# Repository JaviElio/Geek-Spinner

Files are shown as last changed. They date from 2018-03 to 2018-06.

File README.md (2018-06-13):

# Geek-Spinner
POV Spinner

Based on this project: 
	
	- Title:	GEEK SPINNER	
	- Author:	MakersBox
	- Link:		http://www.instructables.com/id/Geek-Spinner/

**BOM**

	- Attiny84-20SSU
	- 8 x 3 mm Red leds
	- SMD Blue led
	- 8 x 330mOhms resistors
	- Push button
	- CR2032 battery holder: 	https://lcsc.com/product-detail/Battery-Holders-Clips-Contacts_CR2032Curved-feet-3V_C70373.html
	- 2 x 0.1uF capacitors
	- TLE4906 Hall sensor: 		https://lcsc.com/product-detail/Sensors_Infineon_TLE4906KHTSA1_TLE4906KHTSA1_C126652.html
	- SMD switch : 			https://lcsc.com/product-detail/Toggle-Switches_9mm-3-5mm_C92658.html
	- 2x3 header: 			https://lcsc.com/product-detail/Male-Header_Headers-Pins-2-3P-2-54mm-SMD_C124390.html
	- 608 bearing: 			https://www.aliexpress.com/item/New-High-Speed-608-Hybrid-Ceramic-Center-Bearing-For-Fidget-Hand-spinner-ToyBBC/32817310812.html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
	- 2x1mm neodynium magnet:	https://www.aliexpress.com/item/Free-shipping-10PCS-magnets-2mmx1mm-Tiny-Disc-Neodymium-Rare-Earth-Magnet-2x1-Craft-Model-2-1/32719568312.html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

**3D Model**

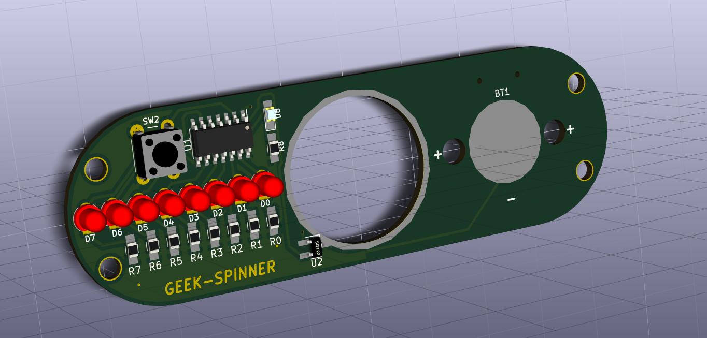
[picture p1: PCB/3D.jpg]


**Video**

POV Spinner (https://www.youtube.com/watch?v=f8Oj__So2bI "POV Spinner")

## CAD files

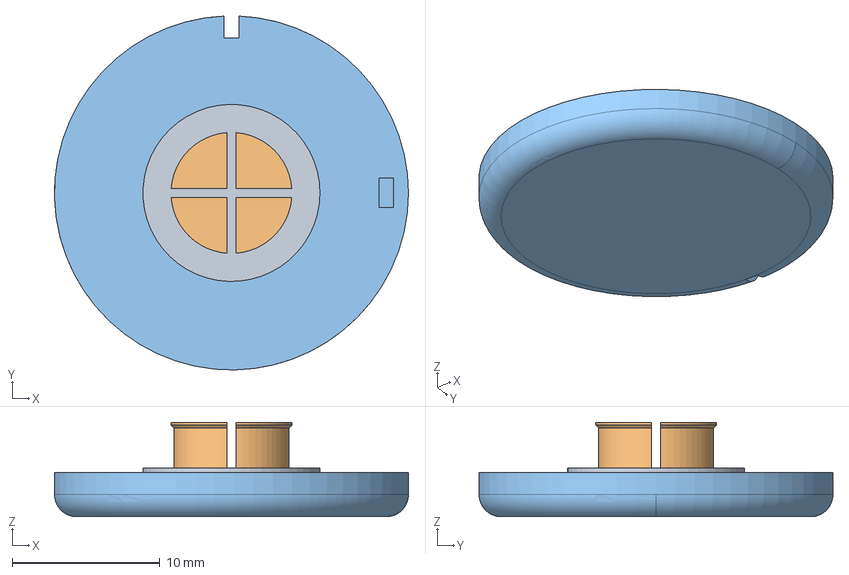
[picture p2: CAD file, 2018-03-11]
Caps/Cap_24mm.fcstd
24.0 x 24.0 x 6.40 mm
Cilindro001

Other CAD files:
Caps/Cap_24mm.stl

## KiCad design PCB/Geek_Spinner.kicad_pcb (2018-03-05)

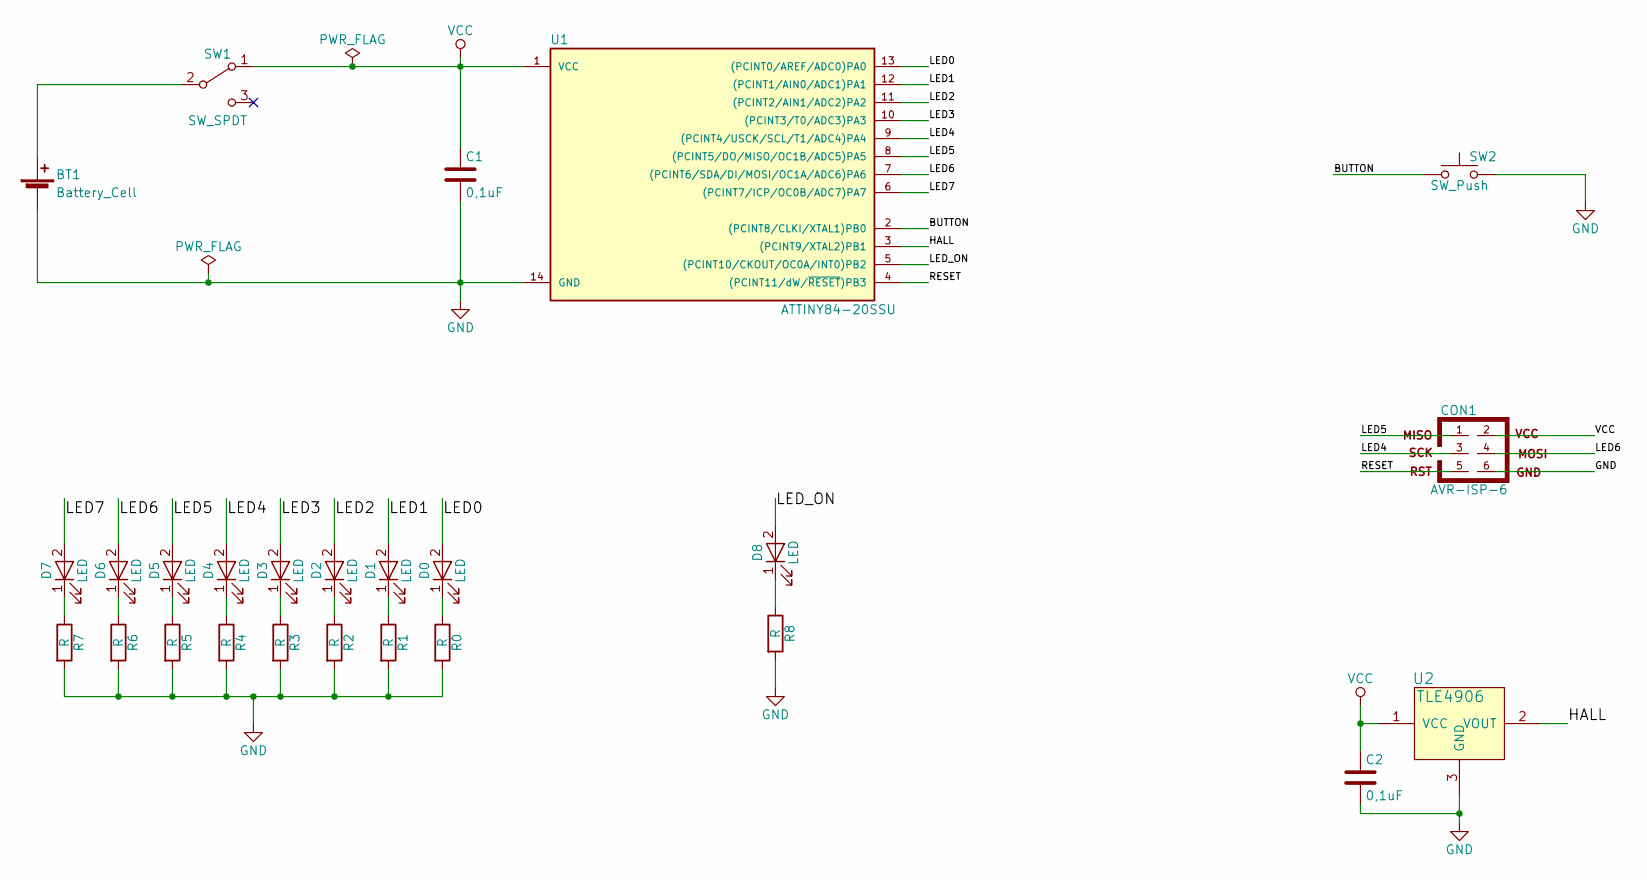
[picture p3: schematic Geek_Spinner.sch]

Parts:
BT1: Battery_Cell; CR2032_Holder_THT
C1, C2: 0,1uF; C_0805_HandSoldering
CON1: AVR-ISP-6; Pin_Header_Straight_2x03_Pitch2.54mm_SMD
D0, D1, D2, D3, D4, D5, D6, D7: LED; LED_D3.0mm
D8: LED; LED_0805_HandSoldering
R0, R1, R2, R3, R4, R5, R6, R7, R8: R; R_0805_HandSoldering
SW1: SW_SPDT; SW_SPDT_CK-JS102011SAQN
SW2: SW_Push; SW_PUSH_6mm_h4.3mm
U1: ATTINY84-20SSU; SOIC-14_3.9x8.7mm_Pitch1.27mm
U2: TLE4906; SC-59_Handsoldering

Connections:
/BUTTON: SW2.1, U1.2 ((PCINT8/CLKI/XTAL1)PB0)
/HALL: U1.3 ((PCINT9/XTAL2)PB1), U2.2 (VOUT)
/LED0: D0.2 (A), U1.13 ((PCINT0/AREF/ADC0)PA0)
/LED1: D1.2 (A), U1.12 ((PCINT1/AIN0/ADC1)PA1)
/LED2: D2.2 (A), U1.11 ((PCINT2/AIN1/ADC2)PA2)
/LED3: D3.2 (A), U1.10 ((PCINT3/T0/ADC3)PA3)
/LED4: CON1.3, D4.2 (A), U1.9 ((PCINT4/USCK/SCL/T1/ADC4)PA4)
/LED5: CON1.1, D5.2 (A), U1.8 ((PCINT5/DO/MISO/OC1B/ADC5)PA5)
/LED6: CON1.4, D6.2 (A), U1.7 ((PCINT6/SDA/DI/MOSI/OC1A/ADC6)PA6)
/LED7: D7.2 (A), U1.6 ((PCINT7/ICP/OC0B/ADC7)PA7)
/LED_ON: D8.2 (A), U1.5 ((PCINT10/CKOUT/OC0A/INT0)PB2)
/RESET: CON1.5, U1.4 ((PCINT11/dW/~RESET~)PB3)
GND: BT1.2 (-), C1.2, C2.2, CON1.6, R0.2, R1.2, R2.2, R3.2, R4.2, R5.2, R6.2, R7.2, R8.2, SW2.2, U1.14 (GND), U2.3 (GND)
unnamed: BT1.1 (+), SW1.2 (B)
unnamed: D0.1 (K), R0.1
unnamed: D1.1 (K), R1.1
unnamed: D2.1 (K), R2.1
unnamed: D3.1 (K), R3.1
unnamed: D4.1 (K), R4.1
unnamed: D5.1 (K), R5.1
unnamed: D6.1 (K), R6.1
unnamed: D7.1 (K), R7.1
unnamed: D8.1 (K), R8.1
VCC: C1.1, C2.1, CON1.2, SW1.1 (A), U1.1 (VCC), U2.1 (VCC)

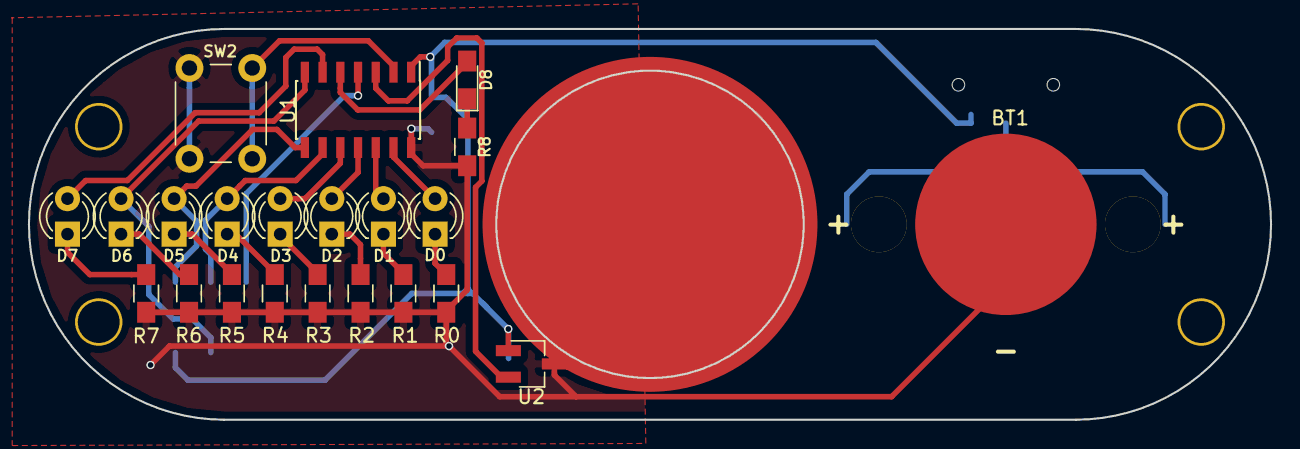
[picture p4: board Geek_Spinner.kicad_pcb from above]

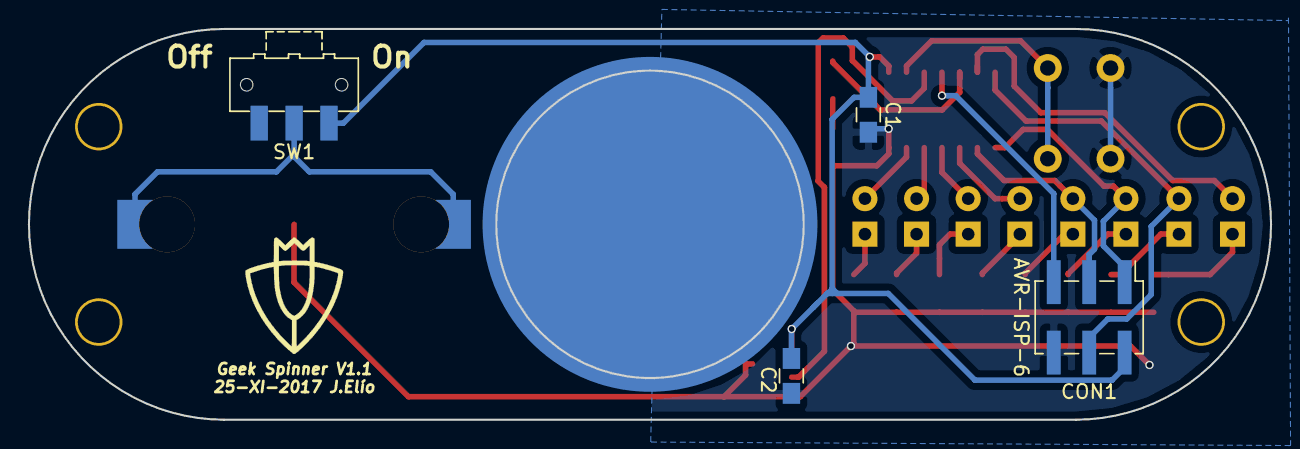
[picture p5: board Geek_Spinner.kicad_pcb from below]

Board: 2 copper layers, 89.0 x 28.0 mm, 26 parts (4 on the bottom side), 24 nets.

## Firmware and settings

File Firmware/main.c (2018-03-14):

/*
 * GeekSpinner.c
 *
 * Created: 21/11/2017 19:54:01
 * Author : javie
 */ 
#define F_CPU	8000000UL

#include <avr/io.h>
#include <stdio.h>
#include <util/delay.h>
#include <avr/interrupt.h>
#include <avr/pgmspace.h>
#include <avr/sleep.h>
#include <avr/wdt.h>
#include "font.h"
#include "textAndShapes.h"


uint8_t spinning = 0;							// spinning -> 1 / not spinning -> 0
volatile uint8_t magnetFlag = 0;				// hall sensor activation flag
uint8_t mode = 1;								// Led mode

volatile uint16_t revs = 0;						// total revolutions
char revsString[6]= "";							// total revolutions (string)
char rpmString[6]="";							// rpm (string)
volatile uint16_t timer0_OV = 0;				// timer overflow counter
volatile uint16_t oldTimer0_OV = 800;			// previous overflow counter
volatile uint16_t millisRev = 0;				// milliseconds per revolution. 


// Magnet sensed interrupt
// calculate time per revolution
ISR (PCINT1_vect) {								// magnet sensed
	if (!(PINB & ( 1 << PINB1))) {

		millisRev = timer0_OV * 0.256;			// Calculate microseconds per revolution
		oldTimer0_OV = timer0_OV;				// Keep overflow counter
		timer0_OV = 0;							// Reset overflow counter
		
		revs++;									// increase revolutions counter
		magnetFlag = 1;							// flag "magnet sensed"
	}
}

// Timer 0 overflow interrupt
// Used to calculate timer per revolution
ISR	(TIM0_OVF_vect) {
	timer0_OV++;
	if (timer0_OV>65500) timer0_OV=65500;
}


ISR(WDT_vect) {

	wdt_disable();  // disable watchdog
}


// Change spinner mode when button is pressed
void ChangeMode(void){							// Change spinner mode
	
	mode++;
	spinning = 0;
	magnetFlag = 0;								
	
	if (mode < 1 || mode > 8) mode = 1;			// Check boundaries
	
	while (!(PINB & (1 << PINB0))) {			// Wait until button is released
		PORTA = (1 << (mode -1));				// Show active mode while button is pressed
		PORTB &= ~(1 << PB2);					// Blue led off
		_delay_ms(50);
	}

	PORTA = 0x00;								// Switch off leds
	PORTB |= (1 << PB2);						// Blue led off
}

// Returns delay in us
uint16_t CalculateDelay(uint16_t inputMillis) {

	return (uint16_t) inputMillis*9.1;
}

// custom delay
void Delay_Us (uint16_t n) {
	
	while(n--) {
		_delay_us(1);
	}
}


//Delay to print lower text
//Functions needs number of character of first line
void DelayLowerText(uint8_t charsFirstLine, uint16_t calculatedDelay) {
	
	// (5 columns x 6 characters) x calculatedDelay;
	Delay_Us( 5*(6-charsFirstLine)*calculatedDelay);
	
}

// Returns number of digits of a given int variable
int8_t NumberOfDigits(uint16_t number) {

	if (number<10) return 1;
	if (number<100) return 2;
	if (number<1000) return 3;
	if (number<10000) return 4;
	if (number<100000) return 5;
	
}


// Print shapes
void ShowShape( const char shape[], uint8_t shapeSize, uint16_t delay){

	for ( int idx=0; idx< shapeSize; idx++)
	{
		PORTA = pgm_read_byte_near(shape+idx);
		Delay_Us(delay);
	}
	
	PORTA = 0x00;
	
};

// Print upper text
void ShowUpperText(const char text[], uint8_t textSize, uint16_t delay) {

	for(int ch=0; ch < textSize; ch++) {										// iterates over each character
				
		for (int col=0; col < 5; col++)											// iterate over each column
		{
			uint8_t column = pgm_read_byte_near(&(font[text[ch]-32][col]));
					
			for (int dot=0; dot < 8; dot++)										// iterate over each dot
			{
				// Swap bits
				if (column & (1 << dot)) PORTA |= (uint8_t) (0x80 >> dot);		// (uint8_t) is necessary,if not the byte is filled with '1'
			}
			Delay_Us(delay);
			PORTA = 0x00;
		}
				
		Delay_Us(delay);
				
	}
}

// Print lower text
void ShowLowerText(const char text[], uint8_t textSize, uint16_t delay) {

	for (int ch = textSize-2; ch>=0; ch--) {									// iterates over each character
		for (int col=4; col>=0; col--)											// iterates over each column
		{
			PORTA = pgm_read_byte_near(&(font[text[ch]-32][col]));
			Delay_Us(delay);
			PORTA=0x00;
		}
		Delay_Us(delay);
	}
}



int main(void)
{

	// Set I/O
	DDRA	=	0xFF;					// PORTA outputs (red leds)
	DDRB	|=	(1 << PB2);				// PB2 output (blue led)
 	DDRB	&=	~(1 << DDB0);			// PB0 input (Button)
 	DDRB	&=  ~(1 << DDB1);			// PB1 input (Hall Sensor)
	PORTB	|=	(1 << PB0);				// Pull-Up resistor
	PORTB	|=	(1 << PB1);				// Pull-Up resistor	

	// Set Timer0
	TCCR0B	|=	(1 << CS01);			// Start timer0 and set prescaler clk/8
	TIMSK0	|=	(1 << TOIE0);			// Enable Overflow Interrupt

	// Reduce power consumption
	ACSR |= (1 << ACD);										// Disable ADC
	PRR	 |= (1 << PRTIM1) | (1 << PRUSI) | (1 << PRADC);	// Disable Timer1, USI and ADC
	set_sleep_mode(SLEEP_MODE_PWR_DOWN);

	// Set interrupt
	PCMSK1	|=	(1 << PCINT9);			// Enable pin interrupt at PB1
	GIMSK	|=	(1 << PCIE1);			// Enable pin change interrupt 1
	sei();								// Enable global interrupts
	
	
	
	
    /* Replace with your application code */
    while (1) 
    {
		
				
		// Change spinner mode
		if (!(PINB & (1 << PINB0)))	ChangeMode();


		
		// If speed is low -> not spinning
		if (oldTimer0_OV >= 800 || timer0_OV > 800)
		{
			spinning = 0;
			PORTB |= (1 << PB2);						// Blue led on
		}
		 else if (oldTimer0_OV < 800)
		 {
			 spinning = 1;
			 PORTB &= ~(1 << PB2);						// Blue led off
		 }
	
	
		 
		 // If spinner is stopped during 16s. (aprox) then sleep
		 if (timer0_OV >= 65500) {
			
			PORTB &= ~(1 << PB2);									// Blue led off
			WDTCSR |= (1 << WDCE) | (1 << WDE);						// Enable WatchDog
			WDTCSR |= (1 << WDIE) | (1 << WDP3);					// Set prescaler to 4s

			sleep_mode();								// go to sleep

			PORTB |= (1 << PB2);						// Blue led on
			_delay_ms(15);
			PORTB &= ~(1 << PB2);						// Blue led off	

		 }
				
	
		
				///////////////////
				// Spinner modes //
				///////////////////


		// Lily pad
		if (mode==1 && spinning==1){
	
			for (int Led=0; Led<8; Led++)
			{
				PORTA = 1 << Led;
				_delay_ms(1);
			}
	
			for (int Led=7; Led > 0;Led--)
			{
				PORTA = 1 << Led;
				_delay_ms(1);
			}

			PORTA = 0x00;

		}		

		
		
		// Smiley
		if (mode==2 && magnetFlag==1 && spinning==1)
		{

			uint16_t calculatedDelay = CalculateDelay(millisRev);	// Calculate delay
			ShowShape(shape_2, sizeof(shape_2), calculatedDelay);	// Show shape
			magnetFlag=0;


		}
	
		
		// Fan
		if (mode==3 && magnetFlag==1 && spinning==1)
		{
			uint16_t calculatedDelay = CalculateDelay(millisRev);	// Calculate delay
			ShowShape(shape_3, sizeof(shape_3), calculatedDelay);	// Show shape
			magnetFlag=0;

		}

	
		
		
		// Heart
		if (mode==4 && spinning == 1 && magnetFlag== 1)
		{

			uint16_t calculatedDelay = CalculateDelay(millisRev);	// Calculate delay
			ShowShape(shape_1, sizeof(shape_1), calculatedDelay);	// Show shape
			magnetFlag=0;

		}		
		
						

		// RPM
		if (mode==5 && magnetFlag==1 && spinning==1){
			
			uint16_t calculatedDelay = CalculateDelay(millisRev);				// Calculate delay
			
			uint16_t rpm = (oldTimer0_OV *0.256);
			rpm = 60000 / rpm;													// Calculate rpm
			sprintf(rpmString, "%d", rpm);										// rpm(int) to string

			ShowUpperText(rpmString, NumberOfDigits(rpm), calculatedDelay);		// Print upper text
			DelayLowerText(NumberOfDigits(rpm), calculatedDelay);				// Wait to print lower text
			ShowLowerText(rpmText,sizeof(rpmText), calculatedDelay);			// Print lower text
			magnetFlag = 0;
			
			
			
		}


		// Total revolutions
		if (mode==6 && magnetFlag ==1 && spinning ==1) {
			
			uint16_t calculatedDelay = CalculateDelay(millisRev);				// Calculate delay for this revolution
			sprintf(revsString, "%d", revs);									// change "int" variable to string

			ShowUpperText(revsString, NumberOfDigits(revs), calculatedDelay);	// Print upper text
			DelayLowerText(NumberOfDigits(revs), calculatedDelay);				// Wait to print lower text
			ShowLowerText(revText, sizeof(revText), calculatedDelay);			// Print lower text
			magnetFlag = 0;
			
		}


		// TEXT		
		if (mode==7 && magnetFlag == 1 && spinning==1) {
			
			uint16_t calculatedDelay = CalculateDelay(millisRev);				// Calculate delay for this revolution

			ShowUpperText(upperText, sizeof(upperText)-1, calculatedDelay);		// Print upper text
			Delay_Us(calculatedDelay*3);										// Delay to print lower text
			ShowLowerText(lowerText, sizeof(lowerText), calculatedDelay);		// Print lower text
			magnetFlag = 0;
			
		}

		if (mode==8 && magnetFlag == 1 && spinning==1) {
			
			static uint8_t repetitionCouneter = 0;
			if (repetitionCouneter>80) repetitionCouneter = 0;

			uint16_t calculatedDelay = CalculateDelay(millisRev);				// Calculate delay for this revolution

			if (repetitionCouneter < 20) {
				ShowShape(shape_1, sizeof(shape_1),calculatedDelay);
				magnetFlag=0;
				repetitionCouneter++;
			}
			
			if (repetitionCouneter >=20 && repetitionCouneter < 40) {
				ShowShape(shape_2, sizeof(shape_2), calculatedDelay);
				magnetFlag=0;
				repetitionCouneter++;
			}
			
			if (repetitionCouneter >=40 && repetitionCouneter < 60) {
				ShowShape(shape_3, sizeof(shape_2),calculatedDelay);
				magnetFlag=0;
				repetitionCouneter++;
			}
			
			if (repetitionCouneter >= 60)
			{

				ShowUpperText(upperText, sizeof(upperText)-1, calculatedDelay);	// Print upper text
				Delay_Us(calculatedDelay*3);									// Delay to print lower text
				ShowLowerText(lowerText, sizeof(lowerText), calculatedDelay);	// Print lower text
				magnetFlag = 0;
				repetitionCouneter++;
			}
			
			
		}
		
    }
}

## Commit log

2018-03-05 First upload
    [24mm_Cap.stl, Cap_24mm.fcstd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]
2018-03-11 indentation added
    [24mm_Cap.stl, Cap_24mm.fcstd, Cap_24mm.stl]
